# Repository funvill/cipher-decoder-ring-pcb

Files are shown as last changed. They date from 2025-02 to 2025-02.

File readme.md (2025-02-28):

# Cipher Decoder Ring PCB

The Cipher Decoder Ring is a toy (not designed for professional use) that allows users to encrypt/decrypt messages using a rotary encoder and LED-guided interface (No screen, or computer required). This toy uses a modern [streaming encryption algorithm](https://en.wikipedia.org/wiki/Stream_cipher) [ChaCha20](https://en.wikipedia.org/wiki/Salsa20#ChaCha_variant) ([RFC7539](https://datatracker.ietf.org/doc/html/rfc7539)) that as of the year 2025 is considered strong encryption (OverKill). A 3D printed dial is fitted over the rotary encoder shaft to mimic a combination lock.

As a backup, when the [RP2040](https://www.raspberrypi.com/products/rp2040/) is connected via USB to a PC, it enumerates as a serial terminal (115200 Baud 8-N-1). A user then could send encoded or decoded messages directly to the serial terminal instead of entering them using the rotary encoder.

Created by: [Steven Smethurst](https://blog.abluestar.com/about) (@funvill)

**!!! Design has not been tested, Sent to manufacturing on 2024-Feb-27 !!!**

## Key Features

- **Stateless Encryption** – No stored keys, no stored state. If this device is captured it can't be used to decode existing encrypted messages.
- **User-Defined Seed & Nonce** – Entered via the rotary encoder for ChaCha20 encryption.
- **Multiple Encryption Modes** – Select from ChaCha20, AES-GCM, ROT13, and more.
- **USB-C Interface** – No battery, and serial interface for encoding binary data.

## How it works

### Step 1 - Select "Encrypt" or "Decrypt"

When the device is powered on

The "Encrypt" LED starts to blink. The user can rotate the dial left or right to switch between "Encrypt" or "Decrypt" mode. When the user has selected the option that they want, they push the dial to confirm their selection.

### Step 2 - Enter seed phase

The "Mode" LED turns red. This indicates that the user can enter a seed phase using the dial. Single click on the dial selects the letter used in the seed phase. A long press on the dial confirms the seed phase is and moves on to the next phase.

### Step 3 - Enter messages

The "Mode" LED turns green. The user can enter the message using the dial one letter at a time. After each letter has been entered the corresponding encoded letter will turn blue. The user writes down the blue letters to encode or decode the message.

## Project Goals

The goal of this project was to learn about [Streaming Cipher](https://en.wikipedia.org/wiki/Stream_cipher) such as [ChaCha20](https://en.wikipedia.org/wiki/Salsa20#ChaCha_variant) as well as making a toy or giveaway for conventions like Hackaday's [SuperCon](https://hackaday.io/superconference/), and Supplyframe's [Teardown](https://www.crowdsupply.com/teardown/).

A secondary goal is to be able to manufacture this board for less then $10 CAD using [JLCPCB](https://jlcpcb.com/) (No manual soldering)

## Technical Specifications

- [Seeed Studio XIAO RP2040](https://wiki.seeedstudio.com/XIAO-RP2040/) microprocessor with USB-C
- [XL-1615RGBC-WS2812B](https://jlcpcb.com/partdetail/XINGLIGHT-XL_1615RGBCWS2812B/C5349954) Individually addressable LEDs
- [EC11E09244BS](https://tech.alpsalpine.com/e/products/detail/EC11E09244BS/) Rotary Encoder

## Tools used

- [KiCad v9.0](https://www.kicad.org/) - EDA
- [EasyEDA2Kicad](https://github.com/uPesy/easyeda2kicad.py) - Converts JLCPCB parts to KiCad files.
- [Gingerbread](https://gingerbread.wntr.dev/index.html) - Converts SVG or Affinity Designer files to KiCad files.

## Preview

### Front

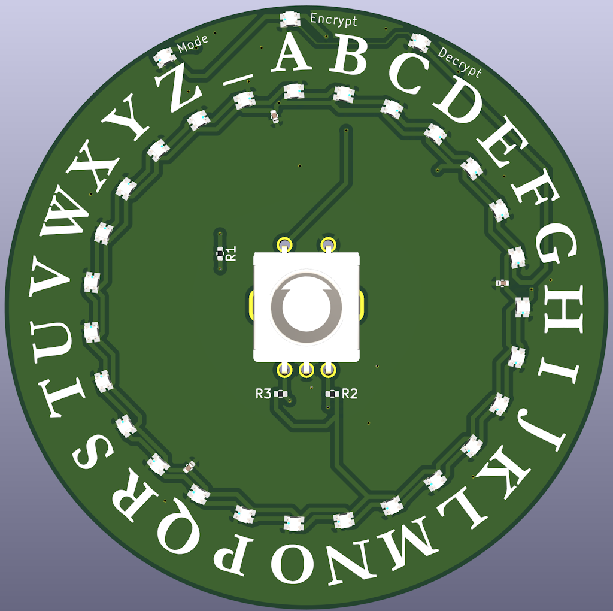
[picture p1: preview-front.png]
Preview-front


### Back

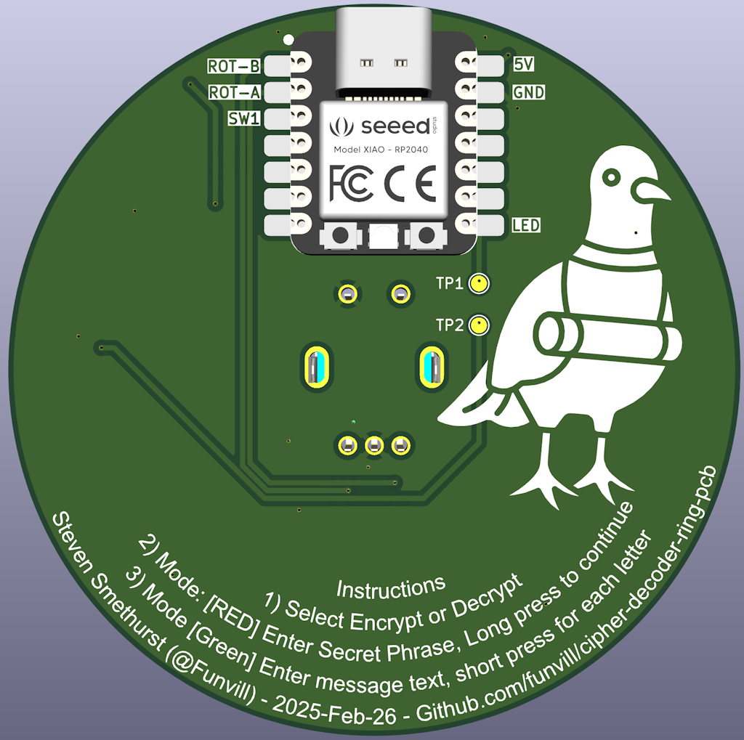
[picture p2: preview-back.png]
Preview-back


### Schematic

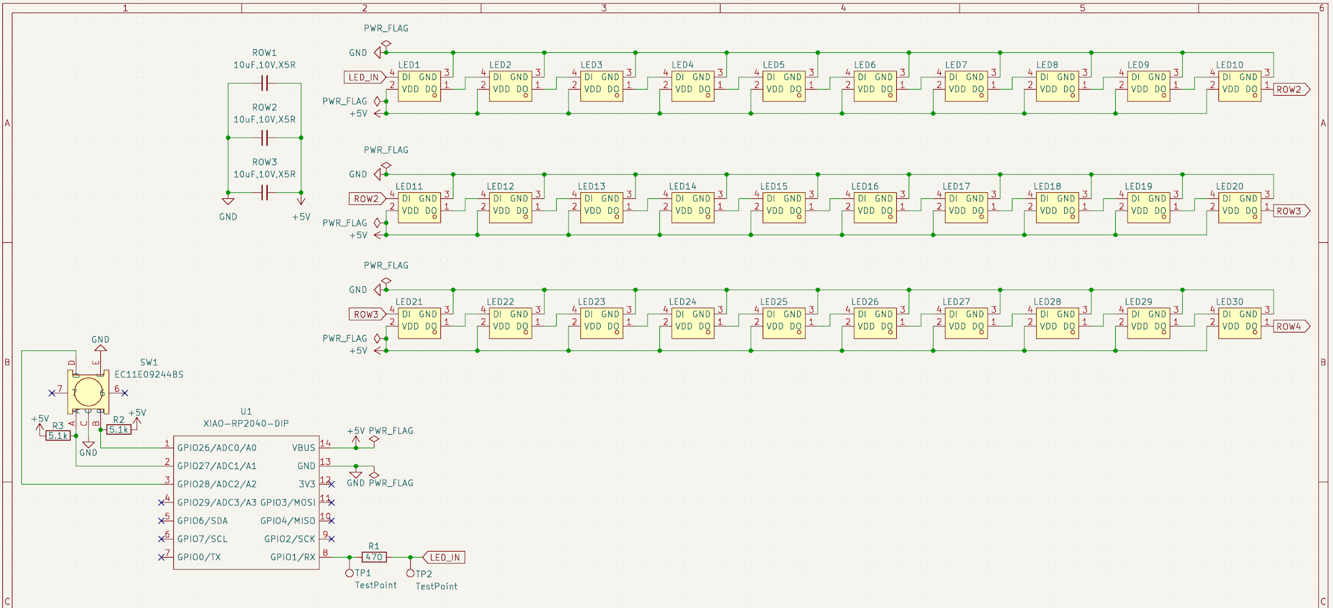
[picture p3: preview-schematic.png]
Preview-back


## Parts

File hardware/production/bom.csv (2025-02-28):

Designator | Footprint | Quantity | Value | LCSC Part #
LED1, LED10, LED11, LED12, LED13, LED14, LED15, LED16, LED17, LED18, LED19, LED2, LED20, LED21, LED22, LED23, LED24, LED25, LED26, LED27, LED28, LED29, LED3, LED30, LED4, LED5, LED6, LED7, LED8, LED9 | LED-SMD_4P-L1.6-W1.5_XL-1615RGBC-WS2812B | 30 | XL-1615RGBC-WS2812B | C5349954
R1 | 0402 | 1 | 470 | C25117
R2, R3 | 0402 | 2 | 5.1k | C25905
ROW1, ROW2, ROW3 | 0402 | 3 | 10uF,10V,X5R | C52923
SW1 | SW-TH_EC11XXXXXXXX | 1 | EC11E09244BS | C470742
TP1, TP2 | TestPoint_Pad_D1.5mm | 2 | TestPoint

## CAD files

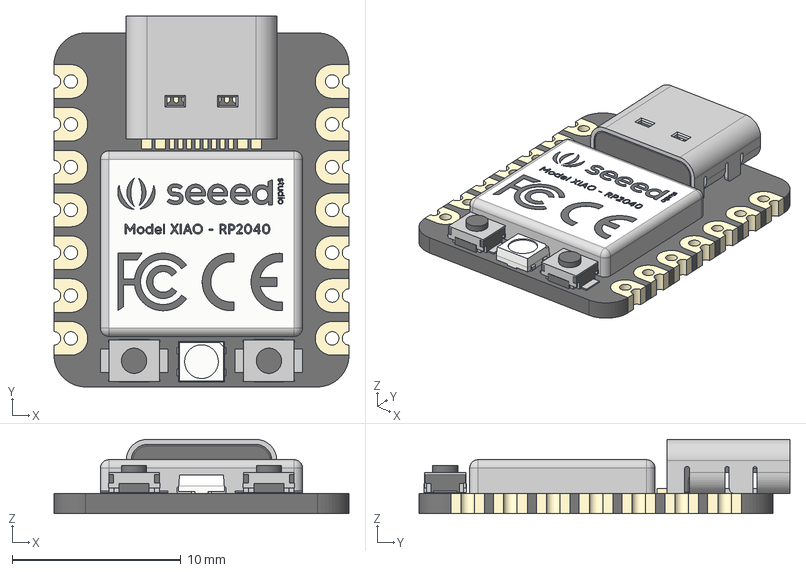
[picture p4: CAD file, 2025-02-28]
hardware/Seeed Studio XIAO/Seeed Studio XIAO RP2040 v26.step
17.5 x 22.0 x 4.40 mm
type-c v2
smd_button v3
DOUT
DIN
VSS
VDD
smd_button v3(Mirror)

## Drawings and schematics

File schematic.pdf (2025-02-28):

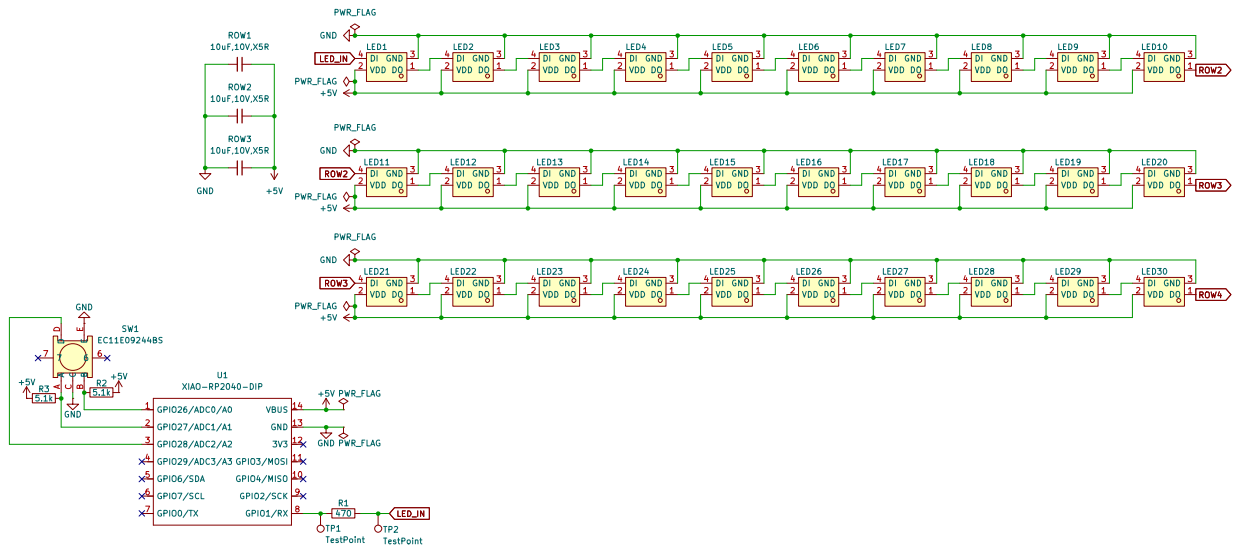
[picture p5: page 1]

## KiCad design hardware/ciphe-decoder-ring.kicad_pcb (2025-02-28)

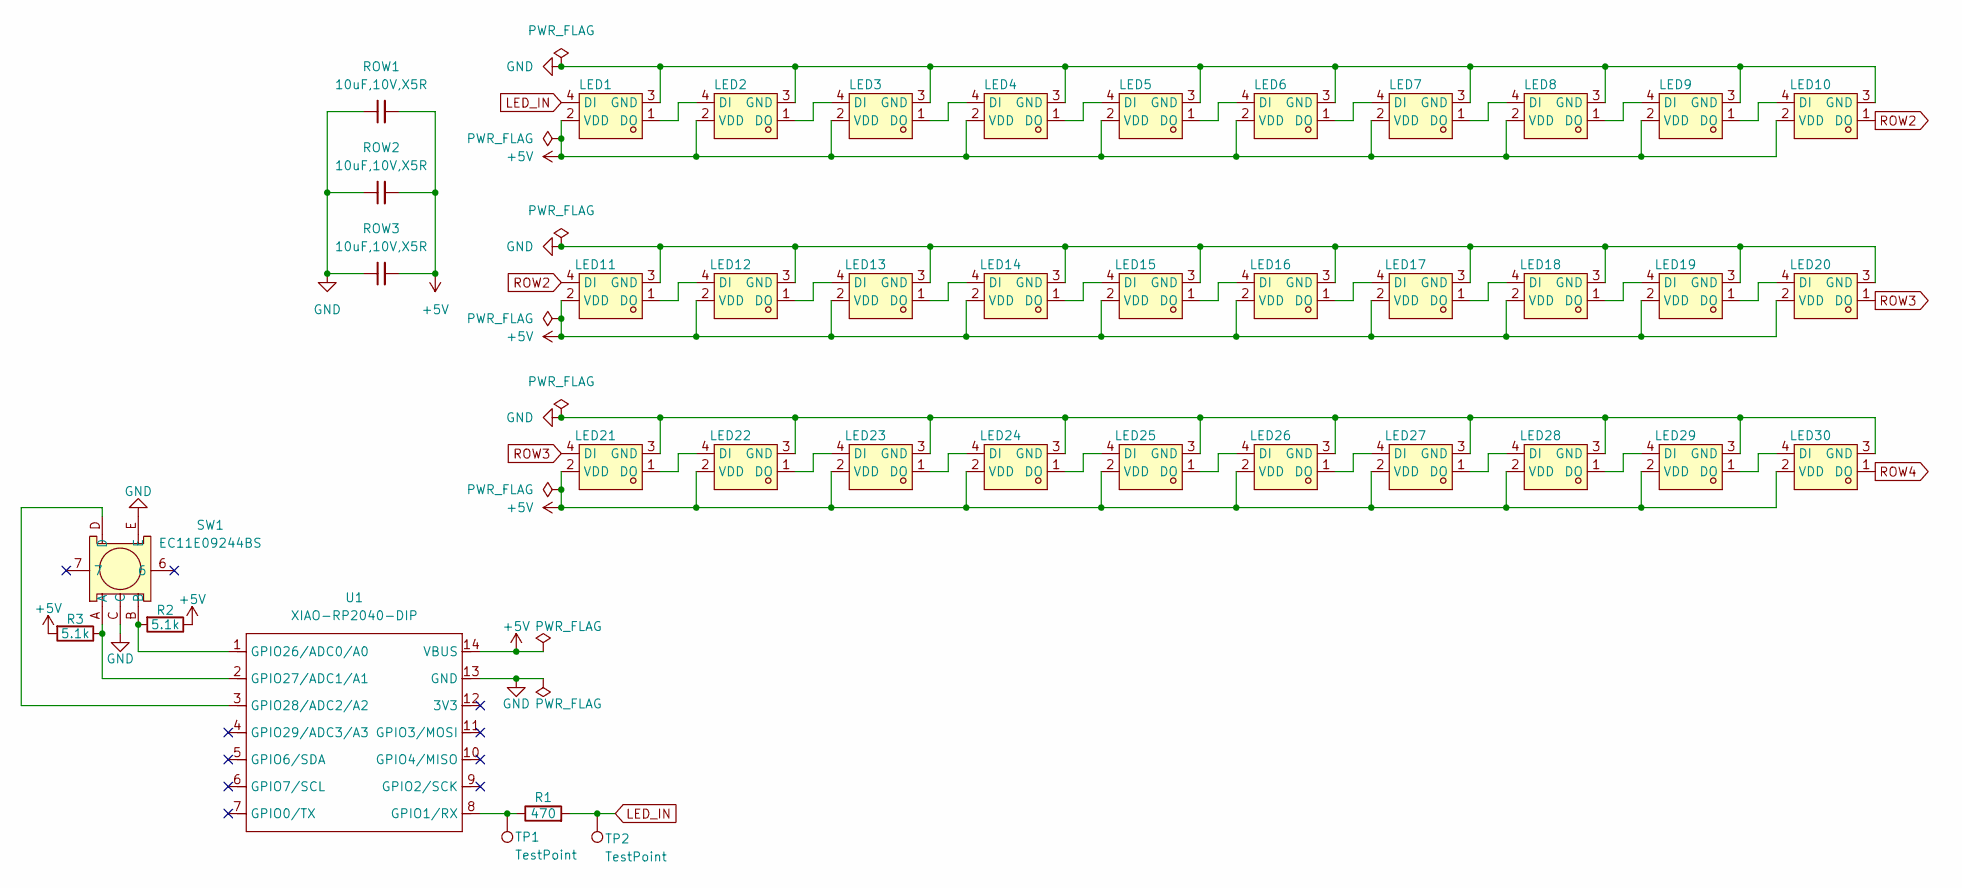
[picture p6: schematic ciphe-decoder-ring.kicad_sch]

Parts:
LED1, LED2, LED3, LED4, LED5, LED6, LED7, LED8, LED9, LED10, LED11, LED12, LED13, LED14, LED15, LED16, LED17, LED18, LED19, LED20, LED21, LED22, LED23, LED24, LED25, LED26, LED27, LED28, LED29, LED30: XL-1615RGBC-WS2812B; LED-SMD_4P-L1.6-W1.5_XL-1615RGBC-WS2812B; LCSC Part C5349954
R1: 470; R_0402_1005Metric; LCSC Part C25117
R2, R3: 5.1k; R_0402_1005Metric; LCSC Part C25905
ROW1, ROW2, ROW3: 10uF,10V,X5R; C_0402_1005Metric; MFGPN CL05A105KA5NQNC; LCSC C52923
SW1: EC11E09244BS; SW-TH_EC11XXXXXXXX; LCSC Part C470742
TP1, TP2: TestPoint; TestPoint_Pad_D1.5mm
U1: XIAO-RP2040-DIP; XIAO-RP2040-SMD

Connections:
+5V: LED1.2 (VDD), LED2.2 (VDD), LED3.2 (VDD), LED4.2 (VDD), LED5.2 (VDD), LED6.2 (VDD), LED7.2 (VDD), LED8.2 (VDD), LED9.2 (VDD), LED10.2 (VDD), LED11.2 (VDD), LED12.2 (VDD), LED13.2 (VDD), LED14.2 (VDD), LED15.2 (VDD), LED16.2 (VDD), LED17.2 (VDD), LED18.2 (VDD), LED19.2 (VDD), LED20.2 (VDD), LED21.2 (VDD), LED22.2 (VDD), LED23.2 (VDD), LED24.2 (VDD), LED25.2 (VDD), LED26.2 (VDD), LED27.2 (VDD), LED28.2 (VDD), LED29.2 (VDD), LED30.2 (VDD), R2.1, R3.2, ROW1.1, ROW2.1, ROW3.1, U1.14 (VBUS)
GND: LED1.3 (GND), LED2.3 (GND), LED3.3 (GND), LED4.3 (GND), LED5.3 (GND), LED6.3 (GND), LED7.3 (GND), LED8.3 (GND), LED9.3 (GND), LED10.3 (GND), LED11.3 (GND), LED12.3 (GND), LED13.3 (GND), LED14.3 (GND), LED15.3 (GND), LED16.3 (GND), LED17.3 (GND), LED18.3 (GND), LED19.3 (GND), LED20.3 (GND), LED21.3 (GND), LED22.3 (GND), LED23.3 (GND), LED24.3 (GND), LED25.3 (GND), LED26.3 (GND), LED27.3 (GND), LED28.3 (GND), LED29.3 (GND), LED30.3 (GND), ROW1.2, ROW2.2, ROW3.2, SW1.C, SW1.E, U1.13 (GND)
LED_IN: LED1.4 (DI), R1.2, TP2.1
unnamed: LED1.1 (DO), LED2.4 (DI)
unnamed: LED2.1 (DO), LED3.4 (DI)
unnamed: LED3.1 (DO), LED4.4 (DI)
unnamed: LED4.1 (DO), LED5.4 (DI)
unnamed: LED5.1 (DO), LED6.4 (DI)
unnamed: LED6.1 (DO), LED7.4 (DI)
unnamed: LED7.1 (DO), LED8.4 (DI)
unnamed: LED8.1 (DO), LED9.4 (DI)
unnamed: LED9.1 (DO), LED10.4 (DI)
unnamed: LED11.1 (DO), LED12.4 (DI)
unnamed: LED12.1 (DO), LED13.4 (DI)
unnamed: LED13.1 (DO), LED14.4 (DI)
unnamed: LED14.1 (DO), LED15.4 (DI)
unnamed: LED15.1 (DO), LED16.4 (DI)
unnamed: LED16.1 (DO), LED17.4 (DI)
unnamed: LED17.1 (DO), LED18.4 (DI)
unnamed: LED18.1 (DO), LED19.4 (DI)
unnamed: LED19.1 (DO), LED20.4 (DI)
unnamed: LED21.1 (DO), LED22.4 (DI)
unnamed: LED22.1 (DO), LED23.4 (DI)
unnamed: LED23.1 (DO), LED24.4 (DI)
unnamed: LED24.1 (DO), LED25.4 (DI)
unnamed: LED25.1 (DO), LED26.4 (DI)
unnamed: LED26.1 (DO), LED27.4 (DI)
unnamed: LED27.1 (DO), LED28.4 (DI)
unnamed: LED28.1 (DO), LED29.4 (DI)
unnamed: LED29.1 (DO), LED30.4 (DI)
unnamed: R1.1, TP1.1, U1.8 (GPIO1/RX)
unnamed: R2.2, SW1.B, U1.1 (GPIO26/ADC0/A0)
unnamed: R3.1, SW1.A, U1.2 (GPIO27/ADC1/A1)
unnamed: SW1.D, U1.3 (GPIO28/ADC2/A2)
ROW2: LED10.1 (DO), LED11.4 (DI)
ROW3: LED20.1 (DO), LED21.4 (DI)
ROW4: LED30.1 (DO)

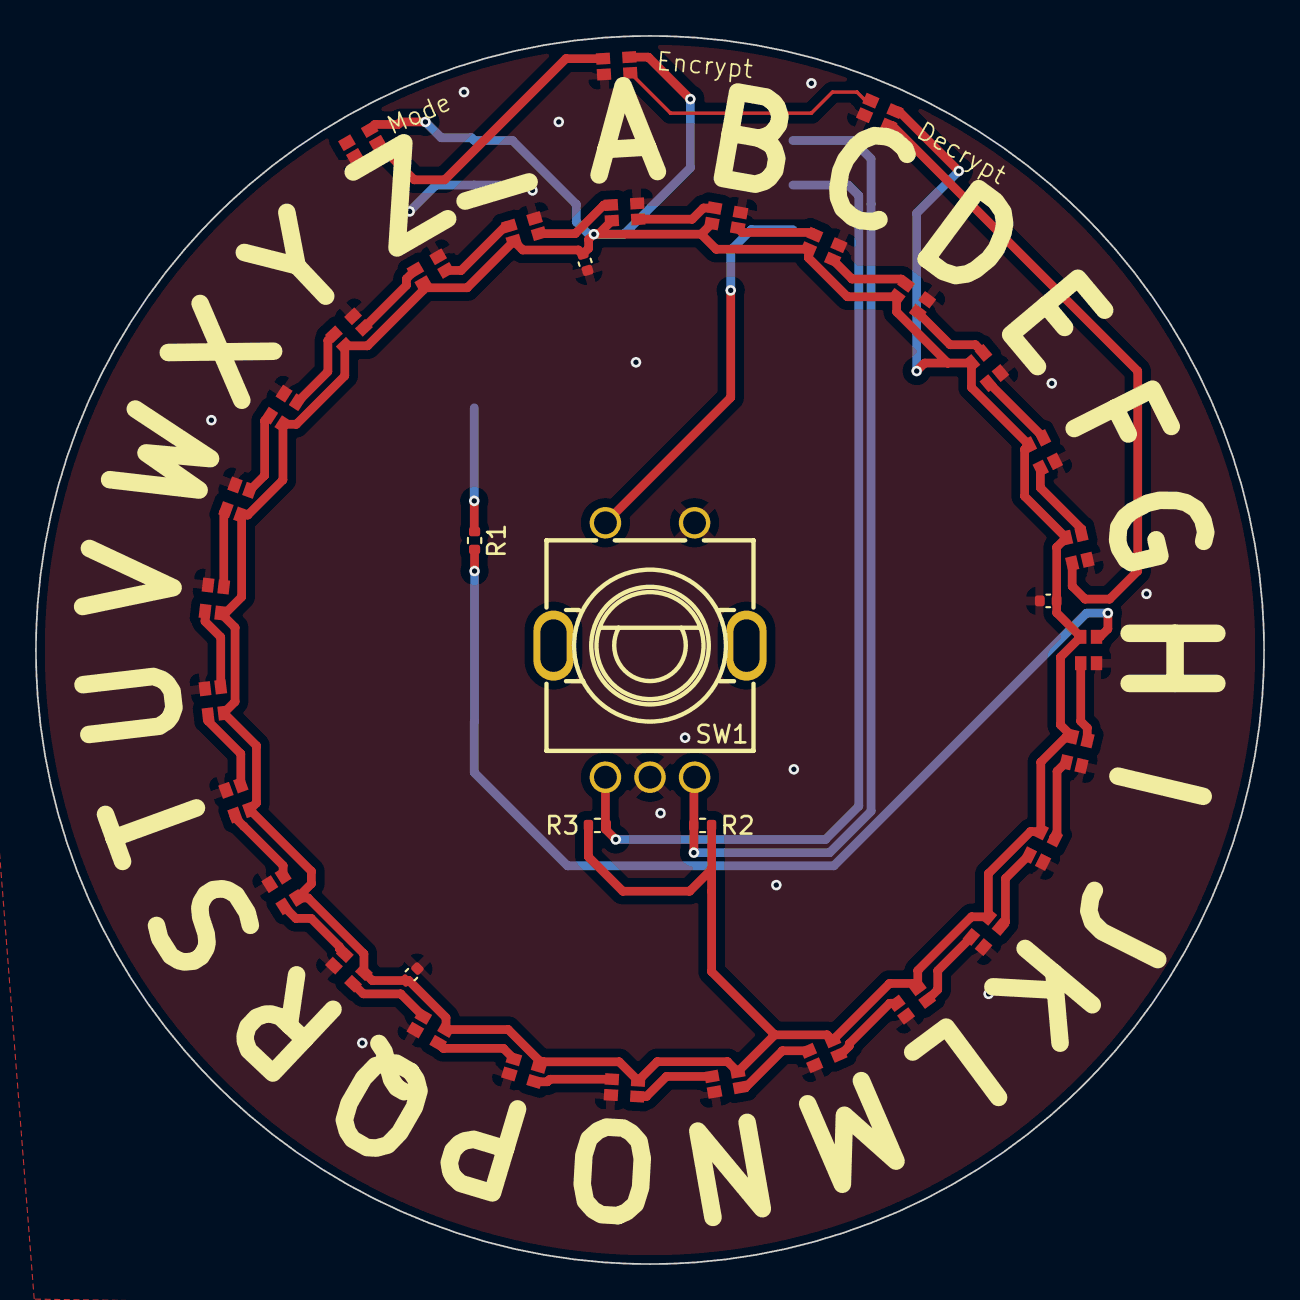
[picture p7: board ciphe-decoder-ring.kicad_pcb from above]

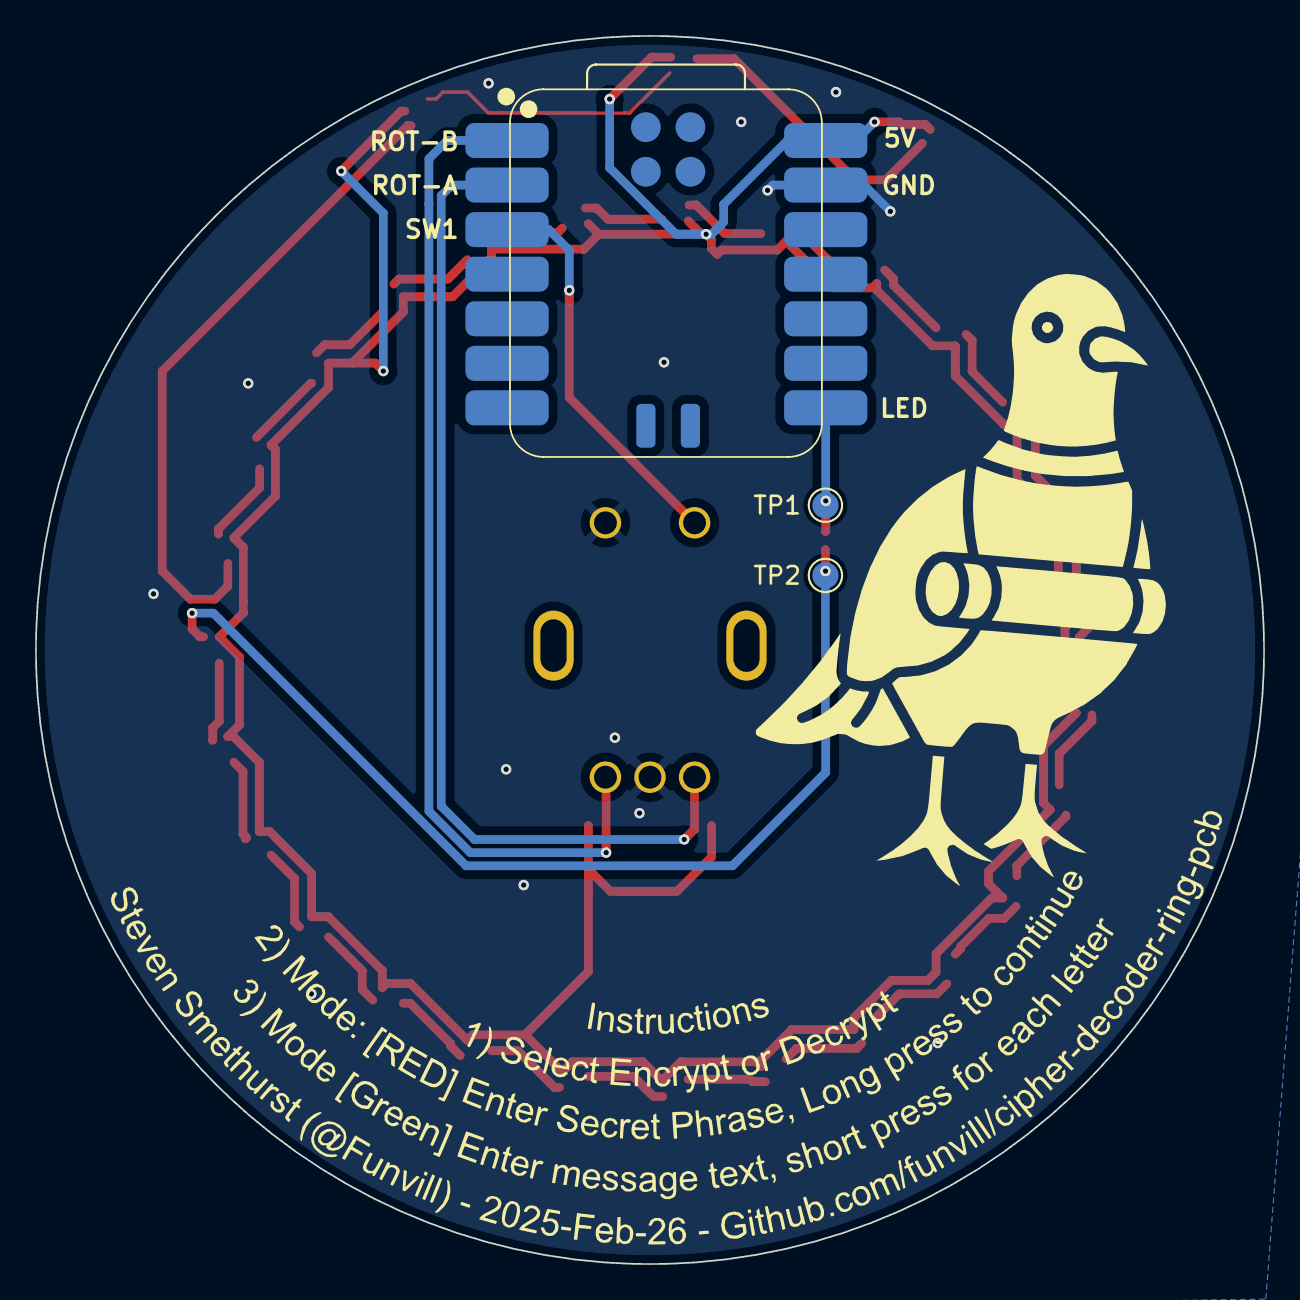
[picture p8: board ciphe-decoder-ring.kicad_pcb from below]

Board: 2 copper layers, 70.0 x 70.0 mm, 40 parts (3 on the bottom side), 36 nets.

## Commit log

2025-02-27 All wired up
    [ciphe-decoder-ring.kicad_pcb, ciphe-decoder-ring.kicad_sch]
2025-02-27 Added preview and instructions
    [ciphe-decoder-ring.kicad_pcb]
2025-02-28 Rotated the letters, Added 3D models to 3D viewer
    [Seeed Studio XIAO RP2040 v26.step, ciphe-decoder-ring.kicad_pcb]
2025-02-28 As manufacured with JLCPCB on 2025-Feb-27
    [bom.csv, ciphe-decoder-ring.kicad_pcb, ciphe-decoder-ring.kicad_sch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]
2025-02-28 Adding schematic as a PDF for review
    [ciphe-decoder-ring.kicad_sch]
